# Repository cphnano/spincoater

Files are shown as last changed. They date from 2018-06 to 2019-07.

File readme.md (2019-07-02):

Spin coater
====

Repository for cphnano's DIY spin coater, for spin coating substrates up to 6".
This repository consists of 3 parts: 
 - spinner_firmware/
   
   This folder contains the arduino-based firmware for controlling the spinner.
   
 - spinner_software/
  
   This folder contains a simple client software for starting, stopping, monitoring and logging spin processes.
 
 - spinner_hardware/
 
   This folder contains CAD files for building the spin coater. 
   
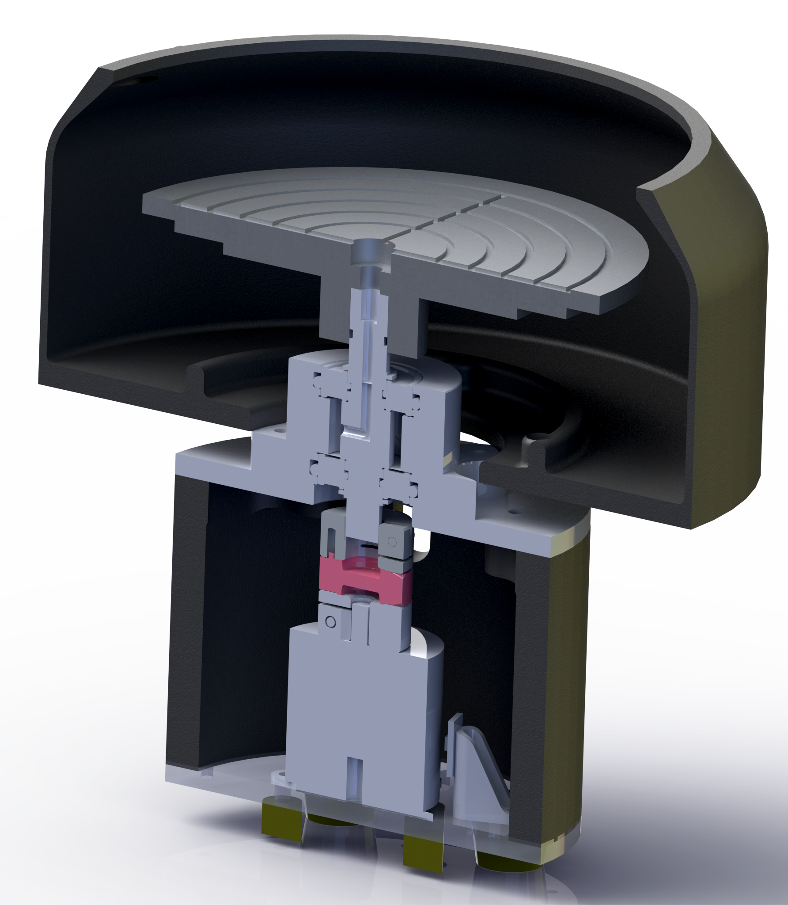
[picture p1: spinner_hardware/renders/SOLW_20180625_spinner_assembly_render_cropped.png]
Spin coater 2


Getting started
-------
**Warning: Spin coaters are dangerous!**
Use at your own risk.
Always take proper safety precautions when working with spinning machines. Cphnano does not take any responsibility for any damages or injuries caused by using the information in this repository. 

 - Start by building the spinner. All the required information can be found in the 'spinner_hardware' folder. If you don't have the resources available  then you can contact 'info@cphnano.com' and we might be able to help you. 
 - Once the hardware has been built, flash the firmware onto the microcontroller. Firmware can be found in the 'spinner_firmware' folder. 
 - Now you should have a functioning spin coater which can be controlled using the software found in 'spinner_software'.

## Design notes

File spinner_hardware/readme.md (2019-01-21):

Hardware
====

Tools required:
-------
 - FDM 3D printer
 - Metal lathe
 - CNC Mill
 - Laser cutter (optional)

Bill of materials:
-----
 - Arduino-compatible microcontroller (Arduino Mega 2560 recommended)
 - BLDC outrunner motor: Low KV, high torque. (AL4263-900KV recommended)
 - ESC: Maytech 45A-OPTO
 - PSU: 12V, 50A or higher. 
 - Tachometer: SparkFun Line Sensor Breakout - QRE1113
 - Flexible vacuum hose (OD = 7mm, ID = 4mm)
 - Couplers: MJC25-10-A, MJC25-6-A, JD16-25-92Y
 - Airtight sealed bearings, 2x: OD = 28mm, ID = 12mm, h = 8mm
 - Circlips, 2x: Ø11.50mm
 - Round aluminium bar (for shaft and chuck)
 - Filament (for 3D printed parts)
 - 5mm PMMA (acrylic) sheet (for lasercut parts)
 - Vibration-dampening rubber feet, 4x: SFF-018
 - Large O-rings, 2x: 26.5x3mm
 - Small O-rings, 3x: 9.25x178mm
 - White and black tape
 - Vacuum ejector: ZH10BS-06-06 

Instructions:
-----
 - Obtain all the materials in 'bill of materials'. 
 - 3D print the following files (found in 'stl' folder).
	* 1x: [SOLW_20170704_vacuum_chamber_for_print.STL](https://github.com/cphnano/spincoater/raw/master/spinner_hardware/STL%20files/SOLW_20170704_vacuum_chamber_for_print.STL)
	* 1x: [SOLW_20170718_Cover.STL](https://github.com/cphnano/spincoater/raw/master/spinner_hardware/STL%20files/SOLW_20170718_Cover.STL)
	* 1x: [SOLW_20170719_Chamber.STL](https://github.com/cphnano/spincoater/raw/master/spinner_hardware/STL%20files/SOLW_20170719_Chamber.STL)
	* 1x: [SOLW_20170724_tuber_holder.STL](https://github.com/cphnano/spincoater/raw/master/spinner_hardware/STL%20files/SOLW_20170724_tube_holder.STL)
	* 2x: [SOLW_20170724_leg_of_Frequency_sensor.STL](https://github.com/cphnano/spincoater/raw/master/spinner_hardware/STL%20files/SOLW_20170724_leg_of_Frequency_sensor.STL)
	* 1x: [Splash-guard SOLW_20170517_Chamber_inclined.STL](https://github.com/cphnano/spincoater/raw/master/spinner_hardware/STL%20files/SOLW_20170517_Chamber_inclined.STL)

 - Laser cut or 3D print the following files: 
	* 1x: [SOLW_20170719_Bottom.STL](https://github.com/cphnano/spincoater/raw/master/spinner_hardware/STL%20files/SOLW_20170719_Bottom.STL)
	* 1x: [SOLW_20170706_Base_plate.STL](https://github.com/cphnano/spincoater/raw/master/spinner_hardware/STL%20files/SOLW_20170706_Base_plate.STL)

 - Use a metal lathe to create the shaft from aluminium bar stock (see [SOLW_20170704_double_bearing_Shaft_with_Oring_seat.pdf](https://github.com/cphnano/spincoater/raw/master/spinner_hardware/Drawings/SOLW_20170704_double_bearing_Shaft_with_Oring_seat.pdf) for working drawing). The shaft should be tapped with an M5 internal thread. 
 - Use CNC mill for making the chuck (see [SOLW_20170727_chuck.PDF](https://github.com/cphnano/spincoater/raw/master/spinner_hardware/Drawings/SOLW_20170727_chuck.PDF) for working drawing). There is also DXF and DWG files available for CNC in the 'Drawings' folder. 
 - Cover half of the outrunner motor in black tape, and the other half in white tape, such that it alternates between white and black as it spins. This is used by the reflectance sensor to determine rotation speed. 
 - Use a steel M5 bolt and drill a Ø2mm hole through the center. This is for airflow for the vacuum chuck.
 - Assemble the spinner. Refer to [/assembly/SOLW_20180625_spinner_assembly.SLDASM](https://github.com/cphnano/spincoater/raw/master/spinner_hardware/Assembly/SOLW_20180625_spinner_assembly.SLDASM) or the cross-section view found in [/renders/SOLW_20180625_spinner_assembly_render2.png](https://github.com/cphnano/spincoater/raw/master/spinner_hardware/renders/SOLW_20180625_spinner_assembly_render2.png).
 - Mount the chuck to the shaft using the hollow M5 bolt. 
 - Plug one end of the vacuum tube into the vacuum chamber. Plug the other end into the output side of the vacuum ejector. 
 - Connect compressed air to the vacuum ejector. 
 - Connect motor to ESC.
 - Connect ESC to PSU.
 - Connect ESC and tachometer to arduino. 
 - Flash firmware onto arduino (download the firmware from the 'spinner_firmware' folder and upload it to the board like any other arduino program).
 - You are now ready to start spin coating. See 'spinner_software' folder for further instructions.

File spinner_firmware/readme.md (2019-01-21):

Communication protocol
-----
The spincoater can be started, stopped and configured via a USB serial connection. 
It uses a simple serial communication protocol in plain ASCII text at a baudrate of 115200 
(by default, this can be changed in configuration.h). Each command must be ended by a newline character (\n or ASCII value 10).

| Function | Command | Example | 
|:---|:---:|:---:|
| Start ramp up/down | RAMP \<time>;\<RPM> | RAMP 3.5;4000 |
| Stop the spinner | STOP | STOP |
| Calibrate the ESC/motor | START_CALIBRATION | START_CALIBRATION |
| Get calibration table | GET_CALIBRATION | GET_CALIBRATION |
| Get all control parameters (ramp and hold) | GET_PID | GET_PID |
| Sets control parameters for ramp | SET_PID_RAMP \<P>;\<I>;\<D>;\<F> | SET_PID_RAMP 85.0;0.0;0.0;1.0 |
| Sets control parameters for hold | SET_PID_HOLD \<P>;\<I>;\<D>;\<F> | SET_PID_HOLD 85.0;0.0;0.0;1.0 |
| Resets the settings saved in EEPROM to default values (PID and feedforward profiles). Use GET_PID to get the new values. Spinner must be calibrated after an EEPROM reset! | RESET_EEPROM | RESET_EEPROM |

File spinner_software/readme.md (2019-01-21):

FAQ
-----
 - Q: How do I use the spinner software?
 
   A: Download [processing](https://processing.org/) and then open spinner_software/spinner_software.pde

 - Q: The spinner software won't connect! What am I doing wrong? 
 
   A: Make sure that you are connected to the right COM port and using the correct baudrate. This can be set on lines 8 and 9 in spinner_software.pde. Ensure that the arduino is connected and is running the correct firmware.
   
 - Q: How do I make a spin profile?
   
   A: See "Creating spin profiles" below.

Creating spin profiles:
------
You can create a spin profile in a text editor (such as notepad). A spin profile consists of multiple linear ramps in succession. See 'ramp.txt' for an example. This profile does the following: 
 - At 2 seconds, start ramp up to 1500RPM over 3 seconds. 
 - At 7 seconds, ramp up from 1500RPM to 3000RPM over 5 seconds.
 - At 15 seconds, ramp down to 500RPM over 2 seconds. 
 
 As a spin profile this is written as:
 ```
 2.0 3.0 1500.0
 7.0 5.0 3000.0
 15.0 2.0 500.0
 ```
 Each line consists of 3 numbers that describes the ramp: The first number is the time (in seconds) to start the ramp, second number is the duration of the ramp (in seconds) and the last number is the target spin speed (in RPM). 
 
 After each ramp is completed the spinner will hold its speed until the next ramp (or stopped). The starting spin speed of each successive ramp is the ending spin speed of the previous ramp (0RPM for the first ramp). 
 
 This way, a simple spin profile consisting of a linear ramp-up and then holding the speed can be written as a single line. 
 
 Note that the lines must be in the order that the ramps should be performed!

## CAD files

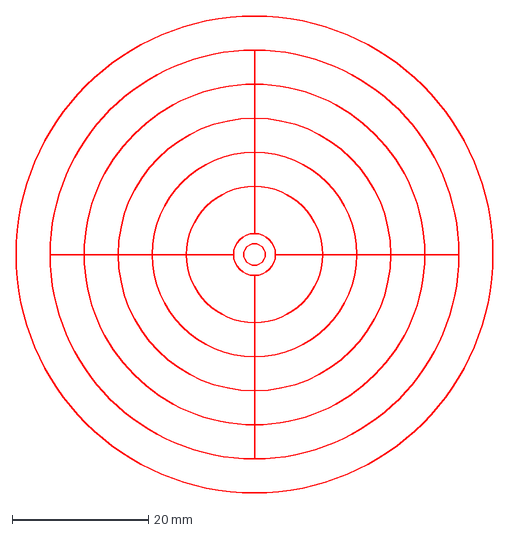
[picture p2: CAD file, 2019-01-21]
spinner_hardware/Drawings/SOLW_20170830_chuck_CNC_file.DXF
70.0 x 70.0 mm

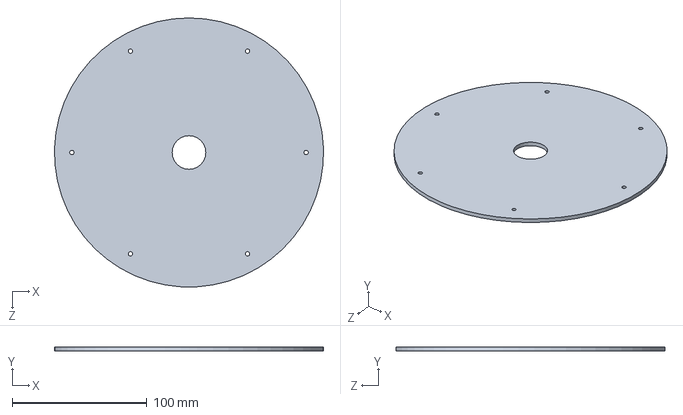
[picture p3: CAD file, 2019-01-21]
spinner_hardware/Parts/SOLW_20170830_Bowl_top.SLDPRT
199.9 x 3.00 x 200.0 mm

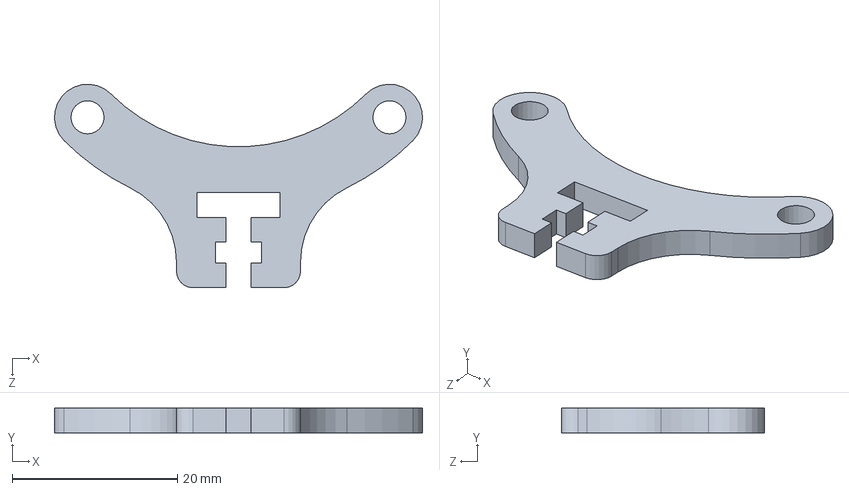
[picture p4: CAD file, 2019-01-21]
spinner_hardware/Parts/SOLW_20170616_Connector.SLDPRT
44.5 x 3.00 x 24.6 mm

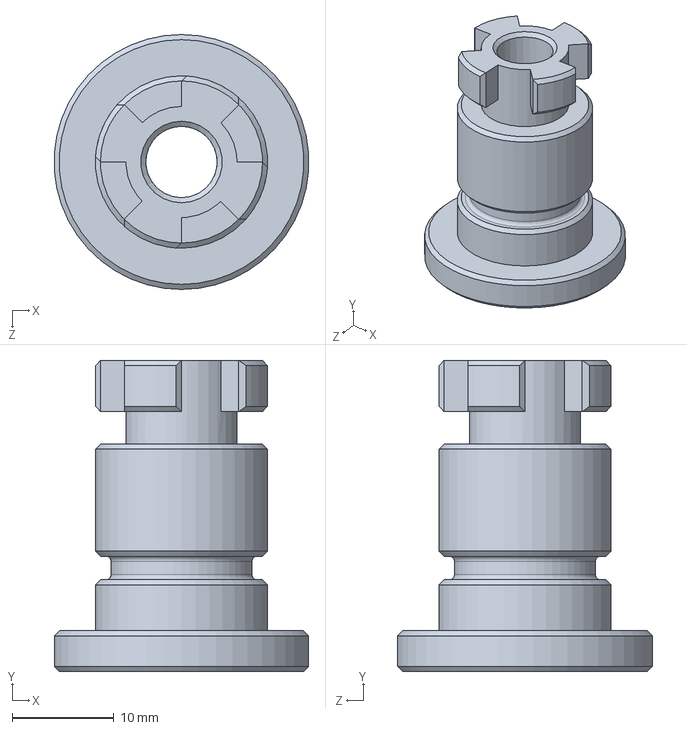
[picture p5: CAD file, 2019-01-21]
spinner_hardware/Parts/SOLW_20170703_Shaft_with_Oring_seat.SLDPRT
24.9 x 30.5 x 25.0 mm

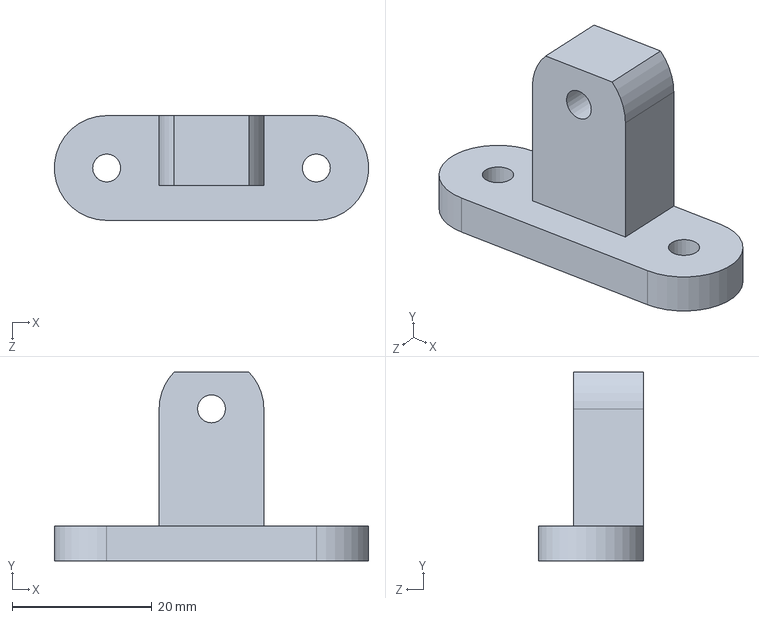
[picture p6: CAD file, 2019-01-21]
spinner_hardware/Parts/SOLW_20170929_PSU_Fixture3.SLDPRT
44.9 x 27.0 x 15.0 mm

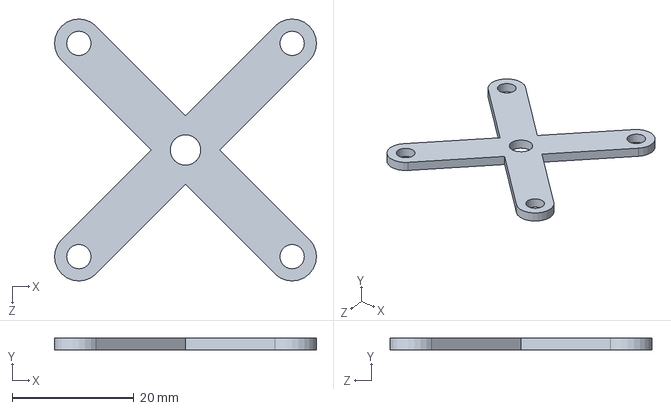
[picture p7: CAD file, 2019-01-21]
spinner_hardware/Parts/SOLW_20170616_Cross.SLDPRT
43.0 x 2.00 x 43.0 mm

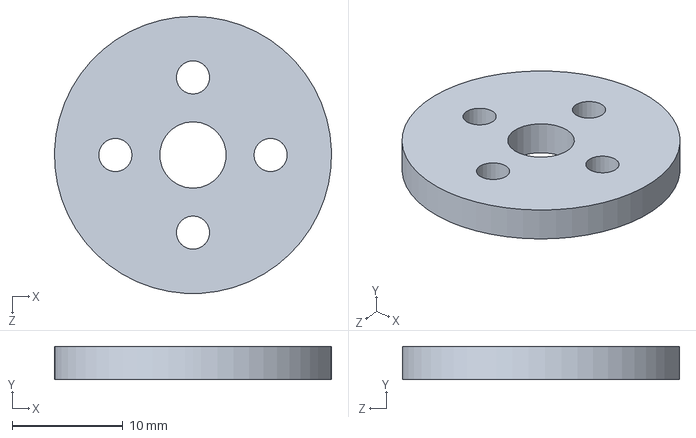
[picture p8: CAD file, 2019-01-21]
spinner_hardware/Parts/SOLW_20170703_spinning_clamp.SLDPRT
25.0 x 3.00 x 25.0 mm

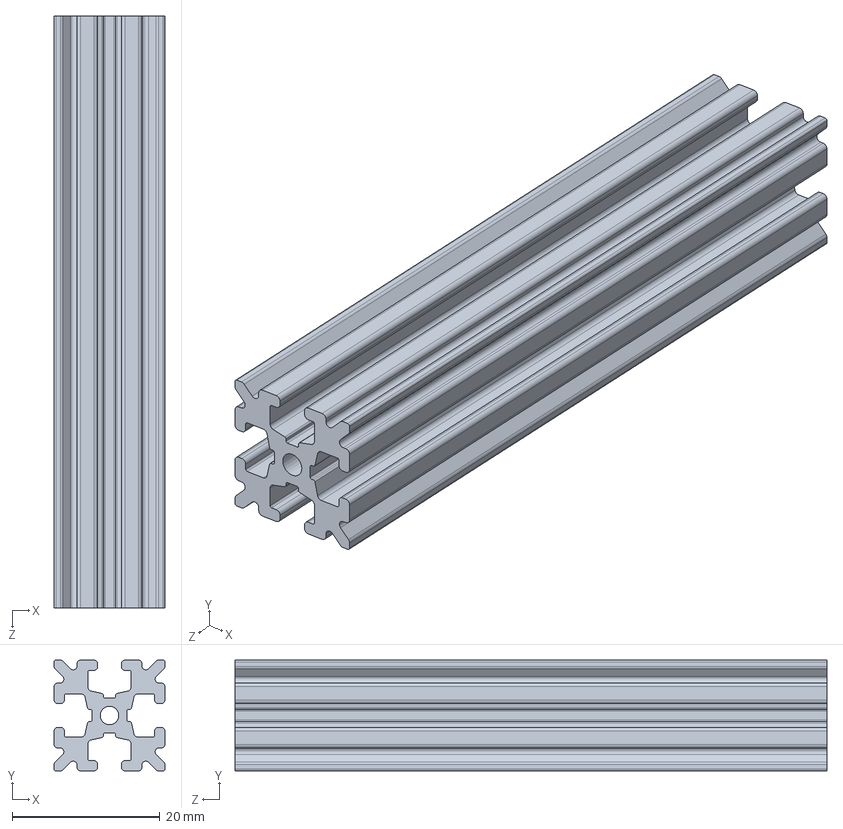
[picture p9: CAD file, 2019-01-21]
spinner_hardware/Parts/SOLW_20170928_Aluminum Profile_4.SLDPRT
15.0 x 15.0 x 80.0 mm

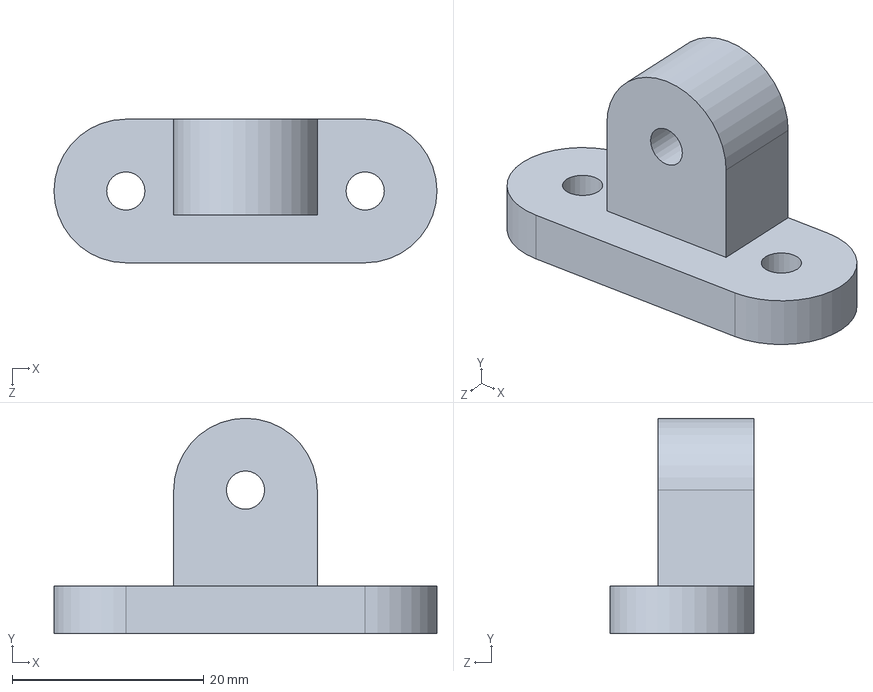
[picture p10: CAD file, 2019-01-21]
spinner_hardware/Parts/SOLW_20170929_PSU_Fixture1.SLDPRT
40.0 x 22.5 x 15.0 mm

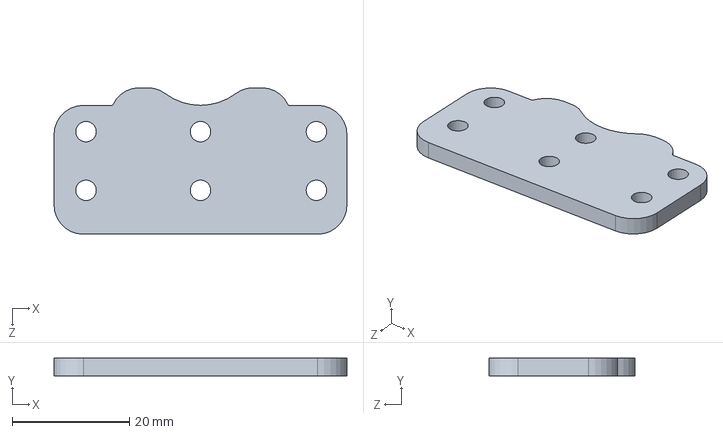
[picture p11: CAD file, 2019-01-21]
spinner_hardware/Parts/SOLW_20170929_Base_of_Frequency_sensor.SLDPRT
50.0 x 3.00 x 25.0 mm

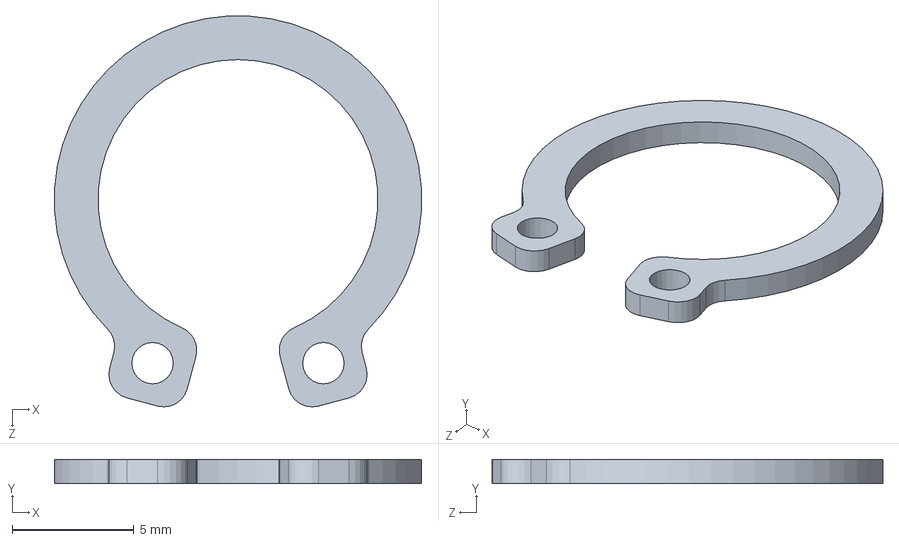
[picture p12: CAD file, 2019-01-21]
spinner_hardware/Parts/SOLW_20170718_Circlips.SLDPRT
15.1 x 1.00 x 16.1 mm

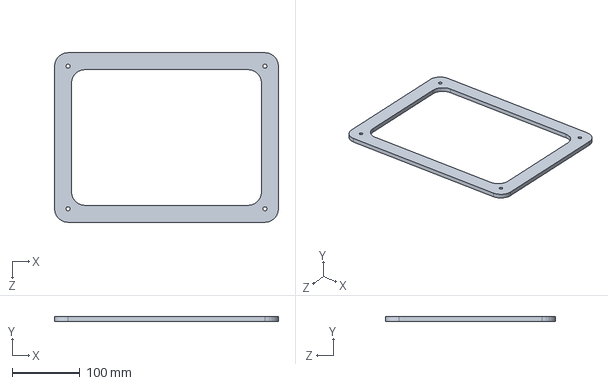
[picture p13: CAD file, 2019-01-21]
spinner_hardware/Parts/SOLW_20180612_Sheet5.SLDPRT
330.0 x 6.90 x 250.0 mm

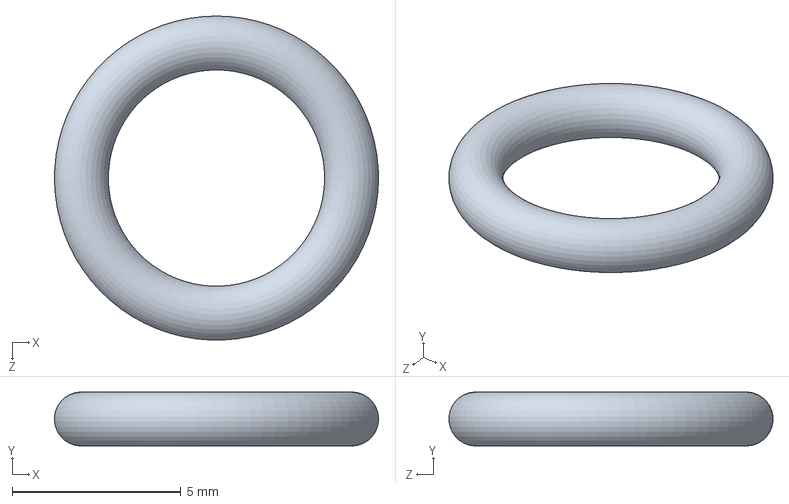
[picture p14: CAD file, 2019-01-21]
spinner_hardware/Parts/SOLW_20170804_O_ring_10X1.6.SLDPRT
9.59 x 1.60 x 9.59 mm

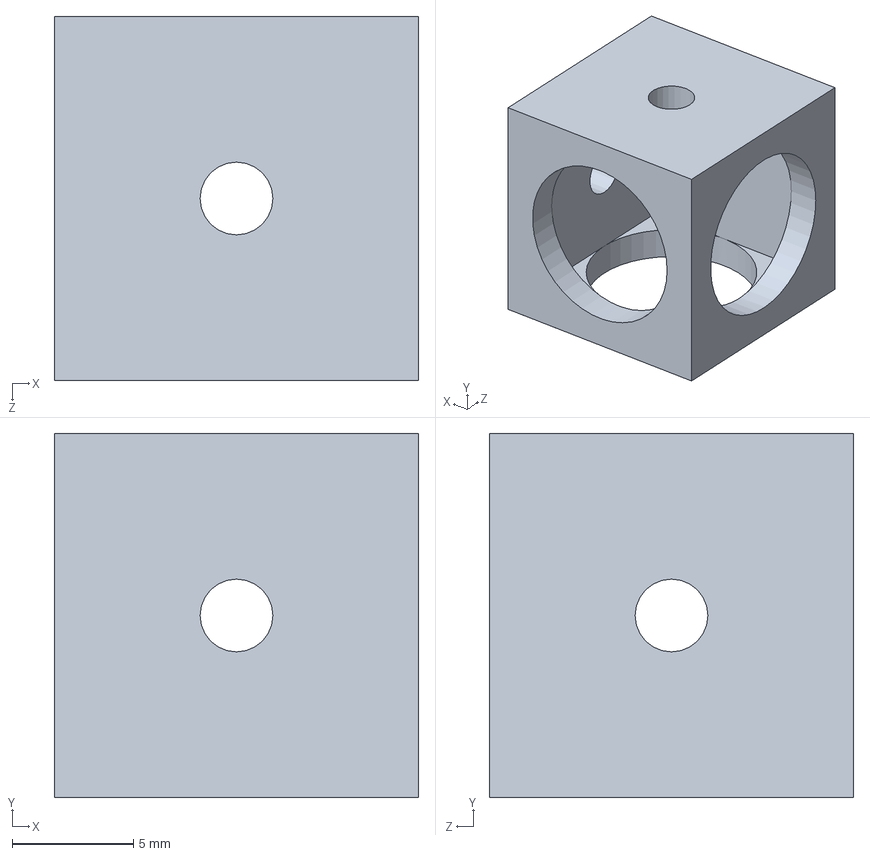
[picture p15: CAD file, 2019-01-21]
spinner_hardware/Parts/SOLW_20170928_corner_cube.SLDPRT
15.0 x 15.0 x 15.0 mm

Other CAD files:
spinner_hardware/Parts/SOLW_20170706_chuck.SLDPRT
spinner_hardware/Parts/SOLW_20170704_coupling.SLDPRT
spinner_hardware/Drawings/SOLW_20170704_double_bearing_Shaft_with_Oring_seat.SLDDRW
spinner_hardware/Drawings/SOLW_20170727_chuck.SLDDRW
spinner_hardware/Drawings/SOLW_20170830_chuck_CNC_file.DWG
spinner_hardware/Drawings/SOLW_20170830_chuck_CNC_file.SLDDRW
spinner_hardware/Parts/SOLW_20170517_Chamber_inclined.SLDPRT
spinner_hardware/Parts/SOLW_20170616_Motor.SLDPRT
spinner_hardware/Parts/SOLW_20170620_chuck_dummy.SLDPRT
spinner_hardware/Parts/SOLW_20170630_test_vacuum_chamber.SLDPRT
spinner_hardware/Parts/SOLW_20170703_17.17X1.78Oring.SLDPRT
spinner_hardware/Parts/SOLW_20170703_9.25X1.78Oring.SLDPRT
spinner_hardware/Parts/SOLW_20170703_Bearing.SLDPRT
spinner_hardware/Parts/SOLW_20170703_Big_washer.SLDPRT
spinner_hardware/Parts/SOLW_20170703_Gasket.SLDPRT
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

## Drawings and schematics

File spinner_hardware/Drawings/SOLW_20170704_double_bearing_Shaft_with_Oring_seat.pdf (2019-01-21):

E E

F F

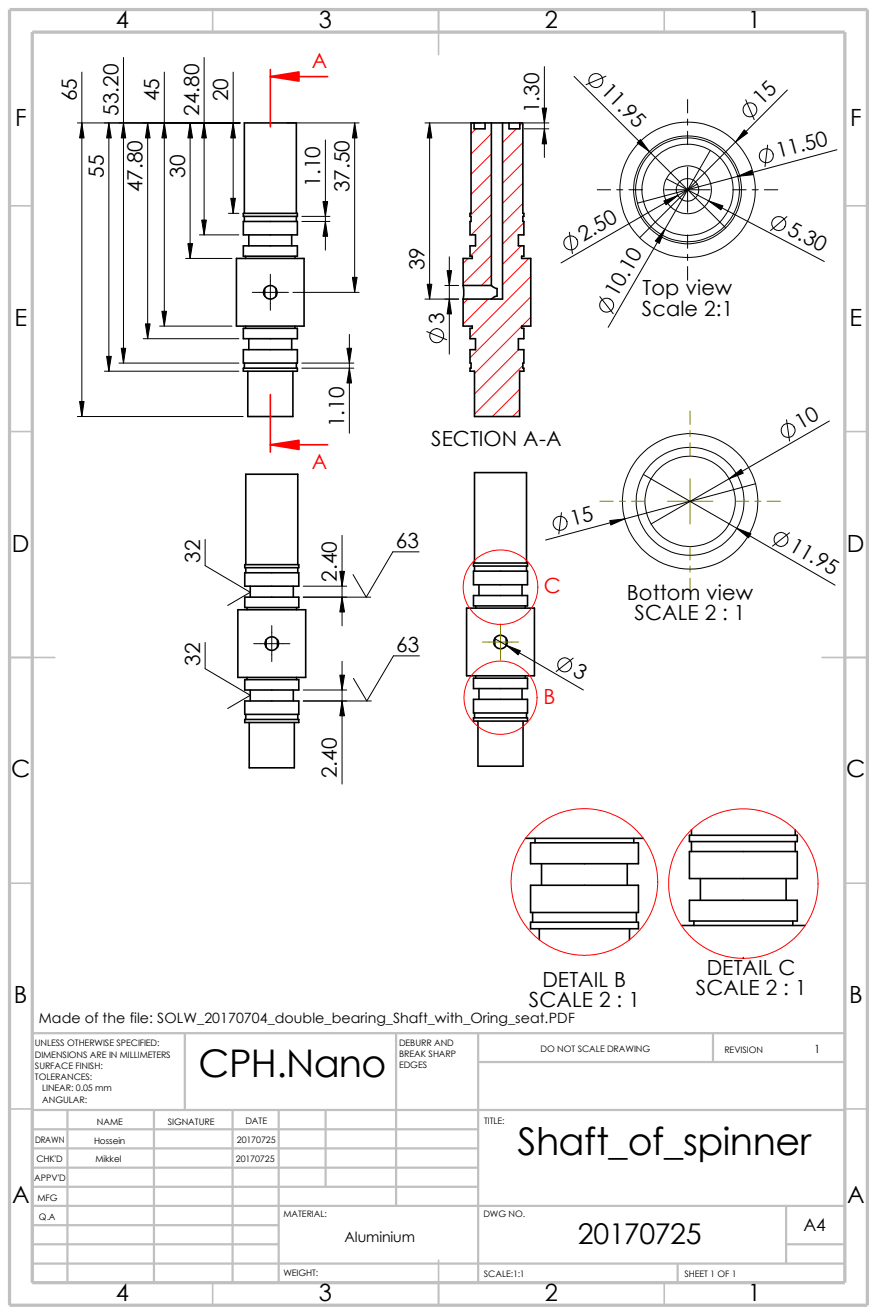
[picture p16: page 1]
DWG NO.; WEIGHT:; Aluminium; REVISION; LINEAR: 0.05 mm; MFG; ANGULAR:; TOLERANCES:; CPH.Nano EDGES; MATERIAL:; SCALE:1:1; SHEET 1 OF 1; DEBURR AND; BREAK SHARP; Bottom view SCALE 2 : 1; DETAIL C SCALE 2 : 1 DETAIL B SCALE 2 : 1; Top view Scale 2:1; SECTION A-A ³ ³⁹

Made of the file: SOLW_20170704_double_bearing_Shaft_with_Oring_seat.PDF

UNLESS OTHERWISE SPECIFIED:
DIMENSIONS ARE IN MILLIMETERS
SURFACE FINISH:

DO NOT SCALE DRAWING

NAME | SIGNATURE | DATE | TITLE: Shaft_of_spinner

DRAWN | Hossein | | 20170725
CHK'D | Mikkel | | 20170725
APPV'D

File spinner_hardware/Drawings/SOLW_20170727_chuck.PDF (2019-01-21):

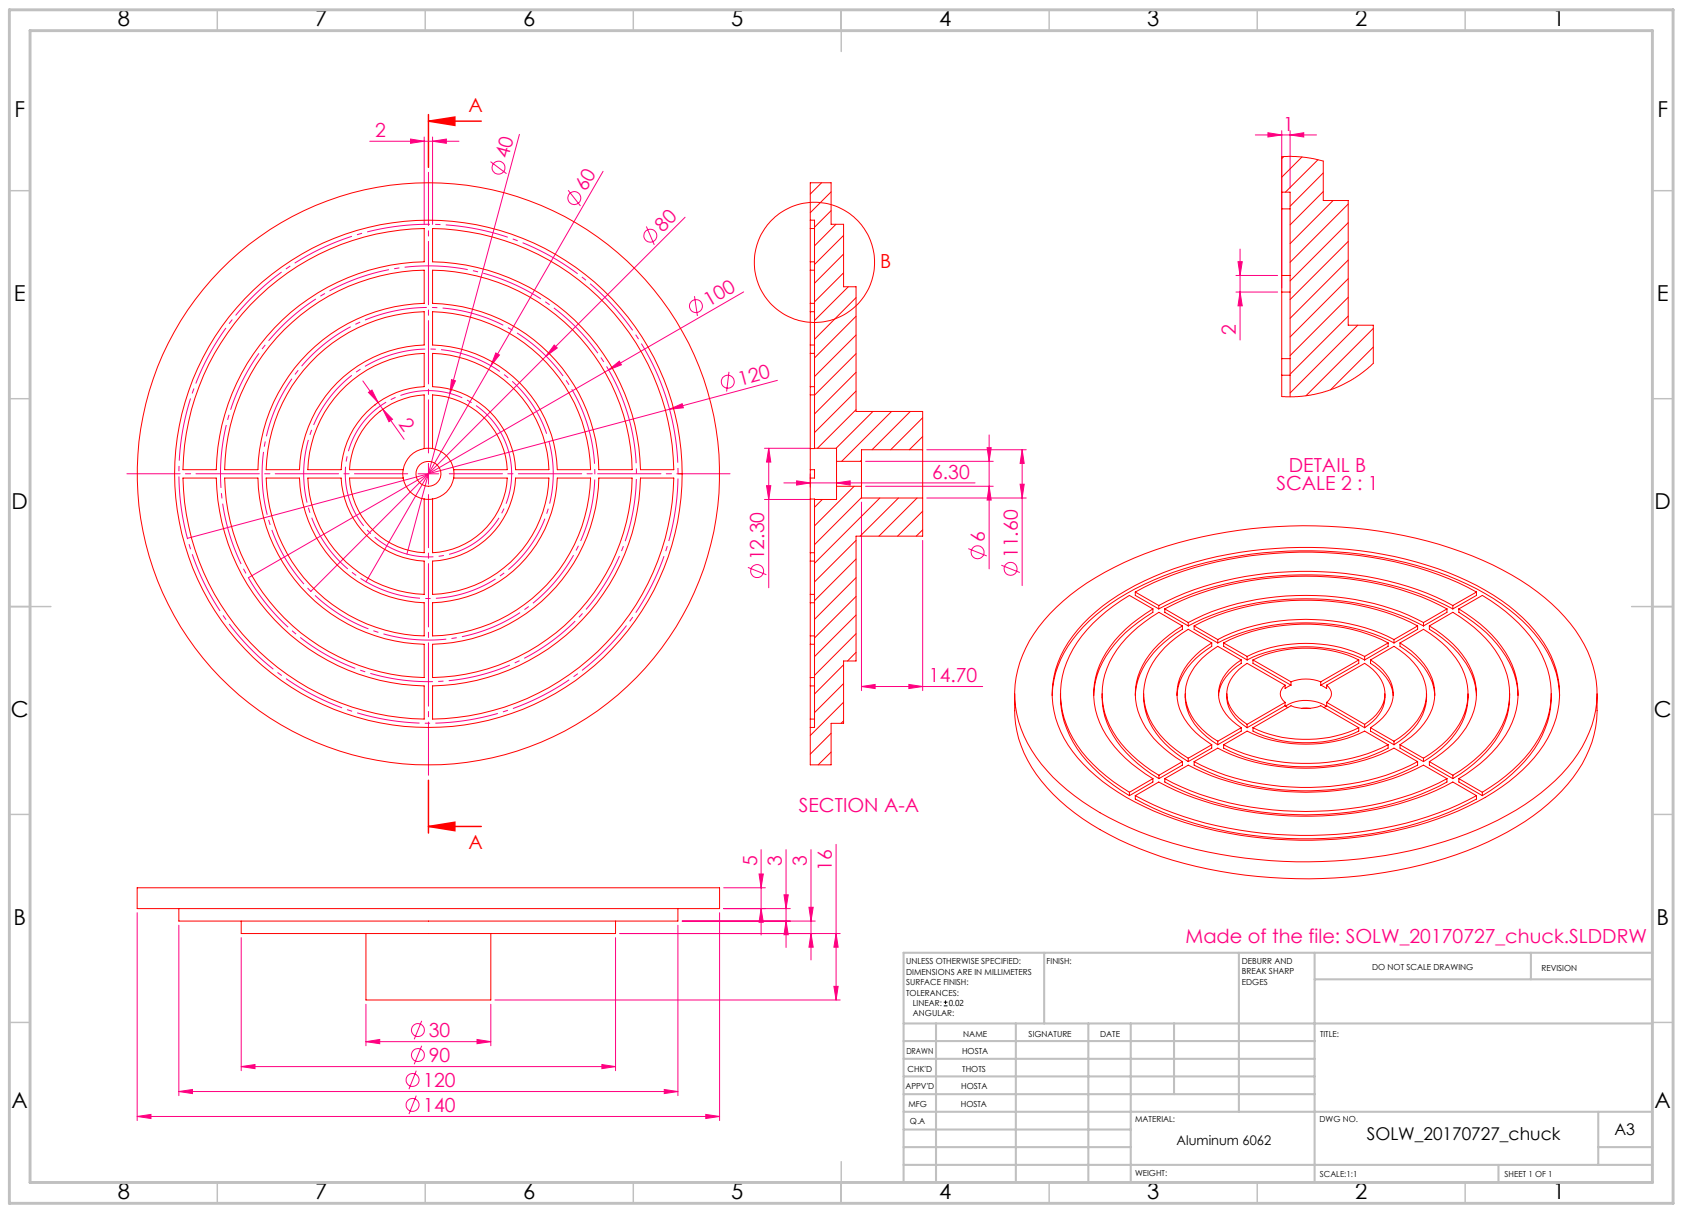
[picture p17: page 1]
SECTION A-A; DETAIL B SCALE 2 : 1; FINISH:; DEBURR AND; BREAK SHARP; DO NOT SCALE DRAWING; REVISION; DWG NO.; SCALE:1:1; SHEET 1 OF 1; A3 Aluminum 6062

Made of the file: SOLW_20170727_chuck.SLDDRW

UNLESS OTHERWISE SPECIFIED:
DIMENSIONS ARE IN MILLIMETERS
SURFACE FINISH:
TOLERANCES:
LINEAR: 0.02
ANGULAR:

CHK'D | THOTS
APPV'D | HOSTA

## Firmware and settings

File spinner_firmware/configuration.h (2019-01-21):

/* CONFIGURATION */
#define ESC_PERIOD         2000L // µs
#define BAUD_RATE        115200
#define RPM_SAMPLES          12 // size of the running average for RPM measurement
#define TACHO_THRES         470 
#define TACHO_HYST          150
#define OUTPUT_SAMPLES        1 // size of the running average for the output throttle

#define READOUT_PERIOD       50 // ms
#define THROTTLE_NEUTRAL   1500 // throttle value for stopping the spinner
#define THROTTLE_MIN       1530 // minimum throttle value where the spinner rotates
#define THROTTLE_MAX       2000 // maximum throttle value
#define THROTTLE_REVERSE   1000 // maximum reverse/brake
#define NUM_THROTTLE          8 // number of throttle values in the LUT. More = more accurate feed-forward, but slower
#define D_SMOOTHING           8 // size of running average for the D term. This eliminates jitter
#define CALIB_TIME        10000 // ms, time spent on each step when doing calibration. This should be long enough for the RPM to settle on a stable value
#define STEADY_THRES          0.08 //8%. When the current RPM is within 8% of the setpoint, the state is switched from RAMP to  STEADY STATE
#define FEEDFORWARD_GAIN      1.0 // gain for the feed-forward term. This can be tuned to use less feed-forward and more PID.
#define SAMPLE_TIME       1000 // µs, sample time for control loop

#define DEFAULT_RAMP_TIME  5000
#define DEFAULT_HOLD_TIME 10000
#define DEFAULT_RPM_GOAL   3000

/***PID parameters***/
//Steady  state
#define DEFAULT_HOLD_KP 51.27 * 0.001
#define DEFAULT_HOLD_KI 35.89 * 0.001
#define DEFAULT_HOLD_KD 0.0
#define DEFAULT_HOLD_KF 1.0
//Ramp
#define DEFAULT_RAMP_KP 85.0 * 0.001
#define DEFAULT_RAMP_KI 0.0
#define DEFAULT_RAMP_KD 0.0
#define DEFAULT_RAMP_KF 1.0

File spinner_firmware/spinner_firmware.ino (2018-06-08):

#include "configuration.h"
#include "pins.h"

unsigned long last_reading = 0;

int state; // -1 = calibration, 0 = do nothing, 1 = ramp up, 2 = hold speed, 3 = ramp down (unused), 4 = spin slowly (for checking alignment)
int calib_step;
unsigned long state_start_time;

// spin cycle configuration. Linear ramp from 0 to rpm_goal over ramp_time number of ms, then hold for hold_time and then linear ramp from rpm_goal to 0 over ramp_time number of ms
long ramp_time = DEFAULT_RAMP_TIME;
long hold_time = DEFAULT_HOLD_TIME;
float rpm_goal = DEFAULT_RPM_GOAL;
float ramp_from = 0;

long throttle;

String instr;

void setup() {
  instr = "";
  Serial.begin(BAUD_RATE);
  throttle = THROTTLE_STOP;

  init_esc();

  init_pid();
  init_tacho();

  arm_esc();
  delay(1000);
}

void loop() {
  // read new commands
  if (Serial.available() > 0) {
    char c = Serial.read();
    if (c == '\n') {
      interpret_command(instr);
      instr = "";
    } else {
      instr = instr + c;
    }
  }

  update_tacho();

  switch (state) {
    case -1:
      run_calibration();
      break;
    case 1:
      spin_ramp_up();
      break;
    case 2:
      spin_steadystate();
      break;
    case 4:
      throttle = THROTTLE_MIN;
      break;
    default:
      throttle = THROTTLE_STOP;
      break;
  }

  update_esc(throttle);

  if (millis() - last_reading > READOUT_PERIOD && state != 0) {
    Serial.print(get_rpm());
    Serial.print(" ");
    Serial.print(get_setpoint());
    Serial.print(" ");
    Serial.println(get_throttle());
    last_reading = millis();
  }
}

void set_state(int new_state) {
  if (state != new_state) {
    state = new_state;

    if (state == -1) {
      calib_step = 0;
    } else if (state == 0){
      init_pid(); // reset integrators
    } else if (state == 1) {
      switch_profile_ramp();
    } else if (state == 2) {
      switch_profile_hold();
    }
    state_start_time = millis();
  }
}

void spin_steadystate() {
  long delta = millis() - state_start_time;
  throttle = compute_throttle(rpm_goal);
}

void spin_ramp_up() {
  long delta = millis() - state_start_time;
  double sp = rpm_goal;
  if (delta < ramp_time) {
    sp = map(delta, 0, ramp_time, ramp_from, rpm_goal);
  } else {
    sp = rpm_goal;
    set_state(2);
  }

  /*double err = rpm_goal - get_rpm();
    if (err < rpm_goal * STEADY_THRES) {
    //switch to steady state
    sp = rpm_goal;
    set_state(2);
    }*/

  throttle = compute_throttle(sp);
}

void run_calibration() {
  //calibration
  long delta = millis() - state_start_time;
  if (delta > CALIB_TIME) {
    update_lut(calib_step, get_rpm(), throttle);
    calib_step++;
    state_start_time = millis();
  }

  if (calib_step < NUM_THROTTLE) {
    throttle = THROTTLE_MIN;
    throttle += (long)(calib_step * ((THROTTLE_MAX - THROTTLE_MIN) / (NUM_THROTTLE - 1)));
  } else {
    throttle = THROTTLE_STOP;
    set_state(0);
  }
}

// change set-point, compute PID and update the ESC
long compute_throttle(double sp) {
  set_setpoint(sp);
  set_input(get_rpm());
  long t = round(compute_pid());
  return t;
}

void set_ramp_time(float new_ramp_time) {
  ramp_time = round(new_ramp_time * 1000);
}

void set_rpm_goal(float new_rpm_goal) {
  rpm_goal = new_rpm_goal;
}

void start_ramp() {
  ramp_from = get_setpoint();
  set_state(1);
}

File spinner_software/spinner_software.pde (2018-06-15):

import controlP5.*;
import processing.serial.*;

int nl = 10; //newline in ASCII

String instr;

int BAUD_RATE = 115200;
int COM_PORT = 0;

Serial port;

boolean connected = false;

boolean profile_loaded = false;

ControlP5 cp5;

PFont roboto;

float[] points_time = new float[0];
float[] points_rpm = new float[0];

float[] ramp_start_times = new float[0];
float[] ramp_times = new float[0];
float[] ramp_rpm = new float[0];
float process_time = 20.0; // Length of time of the spin process, in seconds. Logging stops after this amount of time.
float max_rpm = 5000.0;

long start_time = 0;
int process_step = 0;

boolean spin_started = false;

PrintWriter log_writer;

String profile_filename = "";

void setup() {
  size(800, 600);

  roboto = createFont("Roboto-Regular.ttf", 32);
  textFont(roboto);

  init_gui();

  println("COM PORTS: ");
  printArray(Serial.list());
  connected = connect(COM_PORT, BAUD_RATE);

  if (connected) {
    instr = port.readStringUntil(nl); // throw away the first reading to clear the buffer
    instr = null;
  }
}

boolean load_profile(String filename) {
  profile_filename = filename;
  // reset profile
  ramp_start_times = new float[0];
  ramp_times = new float[0];
  ramp_rpm = new float[0];

  BufferedReader reader = createReader(filename);
  String line = null;
  try {
    while ((line = reader.readLine()) != null) {
      String[] pieces = split(line, " ");
      if (pieces.length == 3) {
        float start = float(pieces[0]);
        float ramp_time = float(pieces[1]);
        float rpm = float(pieces[2]);
        add_ramp(start, ramp_time, rpm);
      }
    }
    reader.close();

    // set process time so logging and plotting matches the spin time
    if (ramp_start_times.length > 0) {
      float end_time = ramp_start_times[ramp_start_times.length-1];
      end_time += ramp_times[ramp_start_times.length-1];
      process_time = end_time + 5.0;
    }

    // set max rpm so the axes fit the data
    max_rpm = 0;
    for (int i = 0; i < ramp_rpm.length; i++) {
      if (ramp_rpm[i] > max_rpm) {
        max_rpm = ramp_rpm[i];
      }
    }
    max_rpm = ceil((max_rpm*1.25)/100)*100;
    profile_loaded = true;
    return true;
  } 
  catch (IOException e) {
    e.printStackTrace();
  }
  return false;
}

void init_gui() {
  cp5 = new ControlP5(this);
  cp5.setAutoDraw(false);


  cp5.addButton("button_start")
    .setPosition(32, 32)
    .setSize(64, 32)
    .setColorForeground(color(130, 184, 58))
    .setColorBackground(color(65, 65, 65))
    .setColorActive(color(0, 255, 0))
    .setLabel("START");

  cp5.addButton("button_stop")
    .setPosition(128, 32)
    .setSize(64, 32)
    .setColorForeground(color(160, 0, 0))
    .setColorBackground(color(65, 65, 65))
    .setColorActive(color(255, 0, 0))
    .setLabel("STOP");

  cp5.addButton("button_load")
    .setPosition(636, 32)
    .setSize(64, 32)
    .setLabel("LOAD PROFILE");

  cp5.addButton("button_calibrate")
    .setPosition(606, 536)
    .setSize(96, 32)
    .setLabel("START CALIBRATION");
}

public void button_start() {
  if (!spin_started && profile_loaded) {
    String timestamp = nf(year(), 4)+nf(month(), 2)+nf(day(), 2);
    timestamp = timestamp+"_"+nf(hour(), 2)+nf(minute(), 2)+nf(second(), 2);
    String filename = "./logs/SPIN_"+timestamp+".txt";
    log_writer = createWriter(filename);
    log_writer.println("Spin profile: "+profile_filename);
    log_writer.println("TIME RPM SETPOINT THROTTLE");
    process_step = 0;
    points_time = new float[0];
    points_rpm = new float[0];
    spin_started = true;
    start_time = millis();
    write_cmd("STOP");
  }
}

public void button_stop() {
  if (spin_started) {
    log_writer.flush();
    log_writer.close();
    write_cmd("STOP");
    spin_started = false;
  }
}

public void button_load() {
  selectInput("Select spincoating profile:", "fileSelected");
}

public void button_calibrate() {
  write_cmd("START_CALIBRATION");
}

void fileSelected(File selection) {
  if (selection == null) {
    println("No file selected");
  } else {
    println("Loading "+selection.getAbsolutePath());
    load_profile(selection.getAbsolutePath());
  }
}
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

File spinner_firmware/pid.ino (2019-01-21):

#include "configuration.h"
#include "pins.h"

unsigned long last_pid_update;
unsigned long ts;
double Kp, Ki, Kd;
double feedforward_gain;
double input, output, setpoint;
double lastErr, lastInput;
double ITerm;
boolean enable_feedforward;

double smoothed_input[D_SMOOTHING];
double total_input;
double current_smooth_input;
double previous_smooth_input;
unsigned int ind_smooth;

double kp_ramp, ki_ramp, kd_ramp, kf_ramp;
double kp_hold, ki_hold, kd_hold, kf_hold;

void init_pid() {
  for (int i = 0; i < D_SMOOTHING; i++) {
    smoothed_input[i] = 0;
  }
  total_input = 0;
  current_smooth_input = 0;
  previous_smooth_input = 0;
  ind_smooth = 0;

  last_pid_update = micros();
  ts = SAMPLE_TIME; //5ms
  input = output = setpoint = 0;
  lastErr = 0;
  lastInput = 0;
  ITerm = 0;
  enable_feedforward = true;

  kp_ramp = DEFAULT_RAMP_KP;
  ki_ramp = DEFAULT_RAMP_KI;
  kd_ramp = DEFAULT_RAMP_KD;
  kf_ramp = DEFAULT_RAMP_KF;

  kp_hold = DEFAULT_HOLD_KP;
  ki_hold = DEFAULT_HOLD_KI;
  kd_hold = DEFAULT_HOLD_KD;
  kf_hold = DEFAULT_HOLD_KF;

  switch_profile_ramp();
}

double compute_pid() {
  unsigned long now = micros();
  double delta_t = (double)(now - last_pid_update);

  if (delta_t >= ts) {
    double error = setpoint - input;
    ITerm += Ki * error;

    output = Kp * error;
    if (enable_feedforward) {
      output += get_feedforward(setpoint * feedforward_gain);
    }

    update_d_input(input);
    double dInput = (current_smooth_input - previous_smooth_input);
    output += Kd * dInput;

    if (setpoint == 0) {
      ITerm = 0;
    } else {
      double IMax = THROTTLE_MAX - output;
      double IMin = THROTTLE_MIN - output;
      if (ITerm > IMax) {
        ITerm = IMax;
      } else if (ITerm < IMin) {
        ITerm = IMin;
      }
    }

    output += ITerm;

    //limit output
    if (setpoint > 0) {
      if (output > THROTTLE_MAX) {
        output = THROTTLE_MAX;
      } else if (output < THROTTLE_MIN) {
        output = THROTTLE_MIN;
      }
    } else {
      output = THROTTLE_NEUTRAL;
    }

    lastErr = error;
    lastInput = input;
    last_pid_update = now;
  }

  return output;
}

void set_input(double inp) {
  input = inp;
}

void set_setpoint(double s) {
  setpoint = s;
}

double get_setpoint() {
  return setpoint;
}

double get_output() {
  return output;
}

void set_pid_parameters(double p, double i, double d, double f) {
  double sample_time = ts / 1000000.0; // convert from µs to s
  Kp = p;
  Ki = i * sample_time;
  Kd = d / sample_time;
  feedforward_gain = f;
}

void set_sample_time(unsigned long t) {
  double sample_time = ts / 1000000.0; // convert from µs to s
  ts = t;
  set_pid_parameters(Kp, Ki / sample_time, Kd * sample_time, feedforward_gain);
}

void switch_profile_ramp() {
  set_pid_parameters(kp_ramp, ki_ramp, kd_ramp, kf_ramp);
}

void switch_profile_hold() {
  set_pid_parameters(kp_hold, ki_hold, kd_hold, kf_hold);
}

void update_d_input(double inp) {
  previous_smooth_input = current_smooth_input;
  total_input -= smoothed_input[ind_smooth];
  total_input += inp;
  current_smooth_input = total_input / D_SMOOTHING;
  smoothed_input[ind_smooth] = inp;
  ind_smooth++;
  if (ind_smooth >= D_SMOOTHING) {
    ind_smooth = 0;
  }
}

double get_feedforward(double r) {
  if (r == 0) {
    return (double)THROTTLE_NEUTRAL;
  }

  if (r <= throttletable[0][0]) {
    return (double)throttletable[0][1];
  } else if (r >= throttletable[NUM_THROTTLE - 1][0]) {
    return (double)throttletable[NUM_THROTTLE - 1][1];
  }

  int r_low, r_high;
  int t_low, t_high;

  for (int i = 1; i < NUM_THROTTLE; i++) {
    if (throttletable[i][0] > r) {
      r_low = throttletable[i - 1][0];
      r_high = throttletable[i][0];
      t_low = throttletable[i - 1][1];
      t_high = throttletable[i][1];
      break;
    }
  }

  double t = (r - r_low);
  t *= (t_high - t_low) * 1.0f;
  t /= ((r_high - r_low) * 1.0f);
  t += t_low;
  return t;
}

void print_parameters() {
  Serial.println("Ramp: ");
  Serial.print("Kp: ");
  Serial.print(kp_ramp, 8);
  Serial.print(", Ki: ");
  Serial.print(ki_ramp, 8);
  Serial.print(", Kd: ");
  Serial.print(kd_ramp, 8);
  Serial.print(", Feedforward: ");
  Serial.println(kf_ramp);
  Serial.println("");
  Serial.println("Steady state: ");
  Serial.print("Kp: ");
  Serial.print(kp_hold, 8);
  Serial.print(", Ki: ");
  Serial.print(ki_hold, 8);
  Serial.print(", Kd: ");
  Serial.print(kd_hold, 8);
  Serial.print(", Feedforward: ");
  Serial.println(kf_hold);
}

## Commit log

2018-05-31 New folder structure
    [configuration.h]
2018-06-04 Refactored firmware into more separate files.
    [configuration.h]
2018-06-04 Bug fixes and refactoring
    [configuration.h]
2018-06-05 Refactored state machine and slightly simplified configuration
    [configuration.h]
2018-06-05 Refactoring and improved tracking
    [configuration.h]
2018-06-07 Arbitrary ramp profiles can now be set over serial and the spinner will automatically switch between PID settings depending on if it's ramping or holding
    [configuration.h]
2018-06-08 Made it easier to switch between PID profiles
    [configuration.h]
2018-06-08 Fixed bug when switching between PID profiles
    [pid.ino, spinner_firmware.ino]
2018-06-15 Fixed bug where loading a new profile would not clear the old profile
    [spinner_software.pde]
2019-01-21 Updated firmware
    [configuration.h]
2019-01-21 Added CAD files
    [SOLW_20170517_Chamber_inclined.SLDPRT, SOLW_20170517_Chamber_inclined.STL, SOLW_20170616_Connector.SLDPRT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]
